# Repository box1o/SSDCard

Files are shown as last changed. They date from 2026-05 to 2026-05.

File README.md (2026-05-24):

# SSDCard 

<p align="center">
  SmartCard Emulator 3D render
</p>

## SmartCard emulator in formfactor of a common Card.
- Size : 85.60 mm × 53.98 mm / reference : ISO/IEC 7810 ID-1 + 50 mm  to the width for the pcb components
- Thickness : 0.76 mm or based on the pcb manufacturer's capabilities

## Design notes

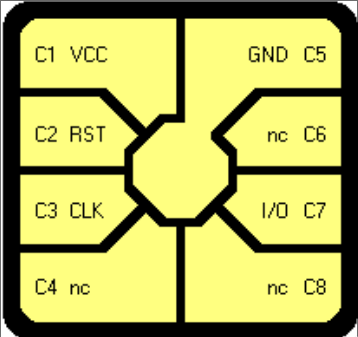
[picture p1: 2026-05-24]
datasheets/pads.png

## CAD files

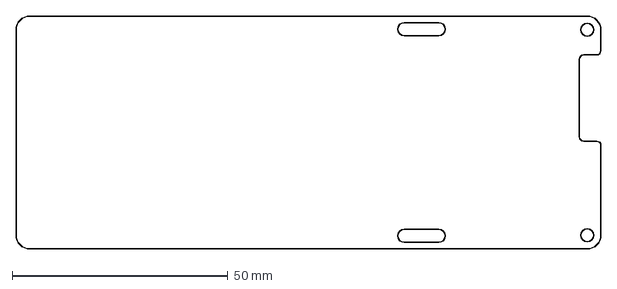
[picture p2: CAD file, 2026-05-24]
mechanical/dxf/BoardOutline.dxf
135.6 x 54.0 mm

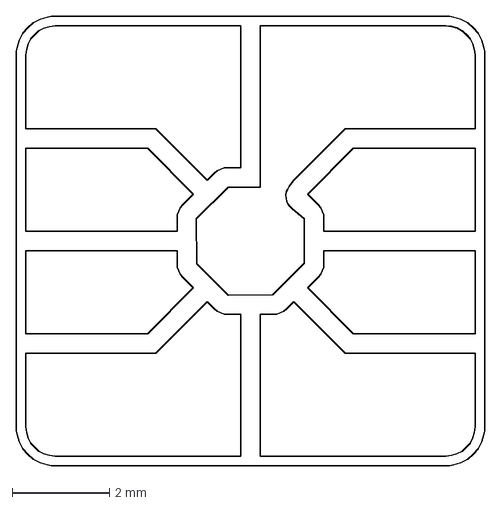
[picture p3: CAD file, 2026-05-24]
mechanical/dxf/cardpads-Sketch-fixed.dxf
9.62 x 9.23 mm

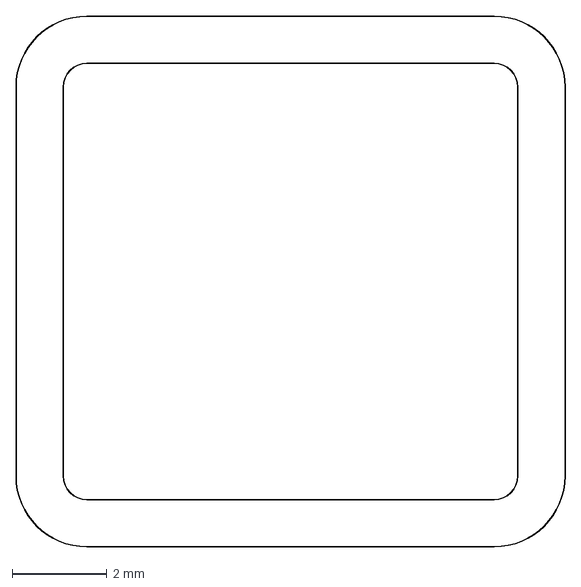
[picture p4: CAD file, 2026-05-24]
mechanical/dxf/ChipOutLine.dxf
11.6 x 11.2 mm

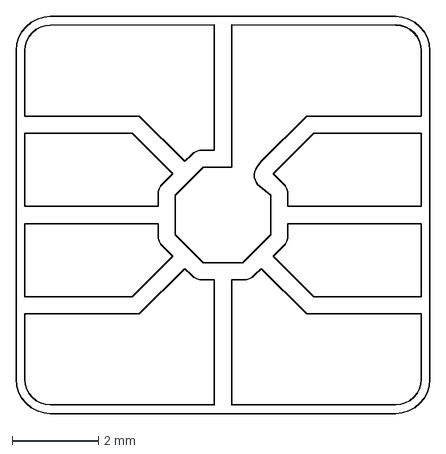
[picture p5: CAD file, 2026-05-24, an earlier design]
mechanical/dxf/outdated.dxf
9.62 x 9.23 mm

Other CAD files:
mechanical/freecad/cardpads.FCStd
mechanical/freecad/Assemple.FCStd

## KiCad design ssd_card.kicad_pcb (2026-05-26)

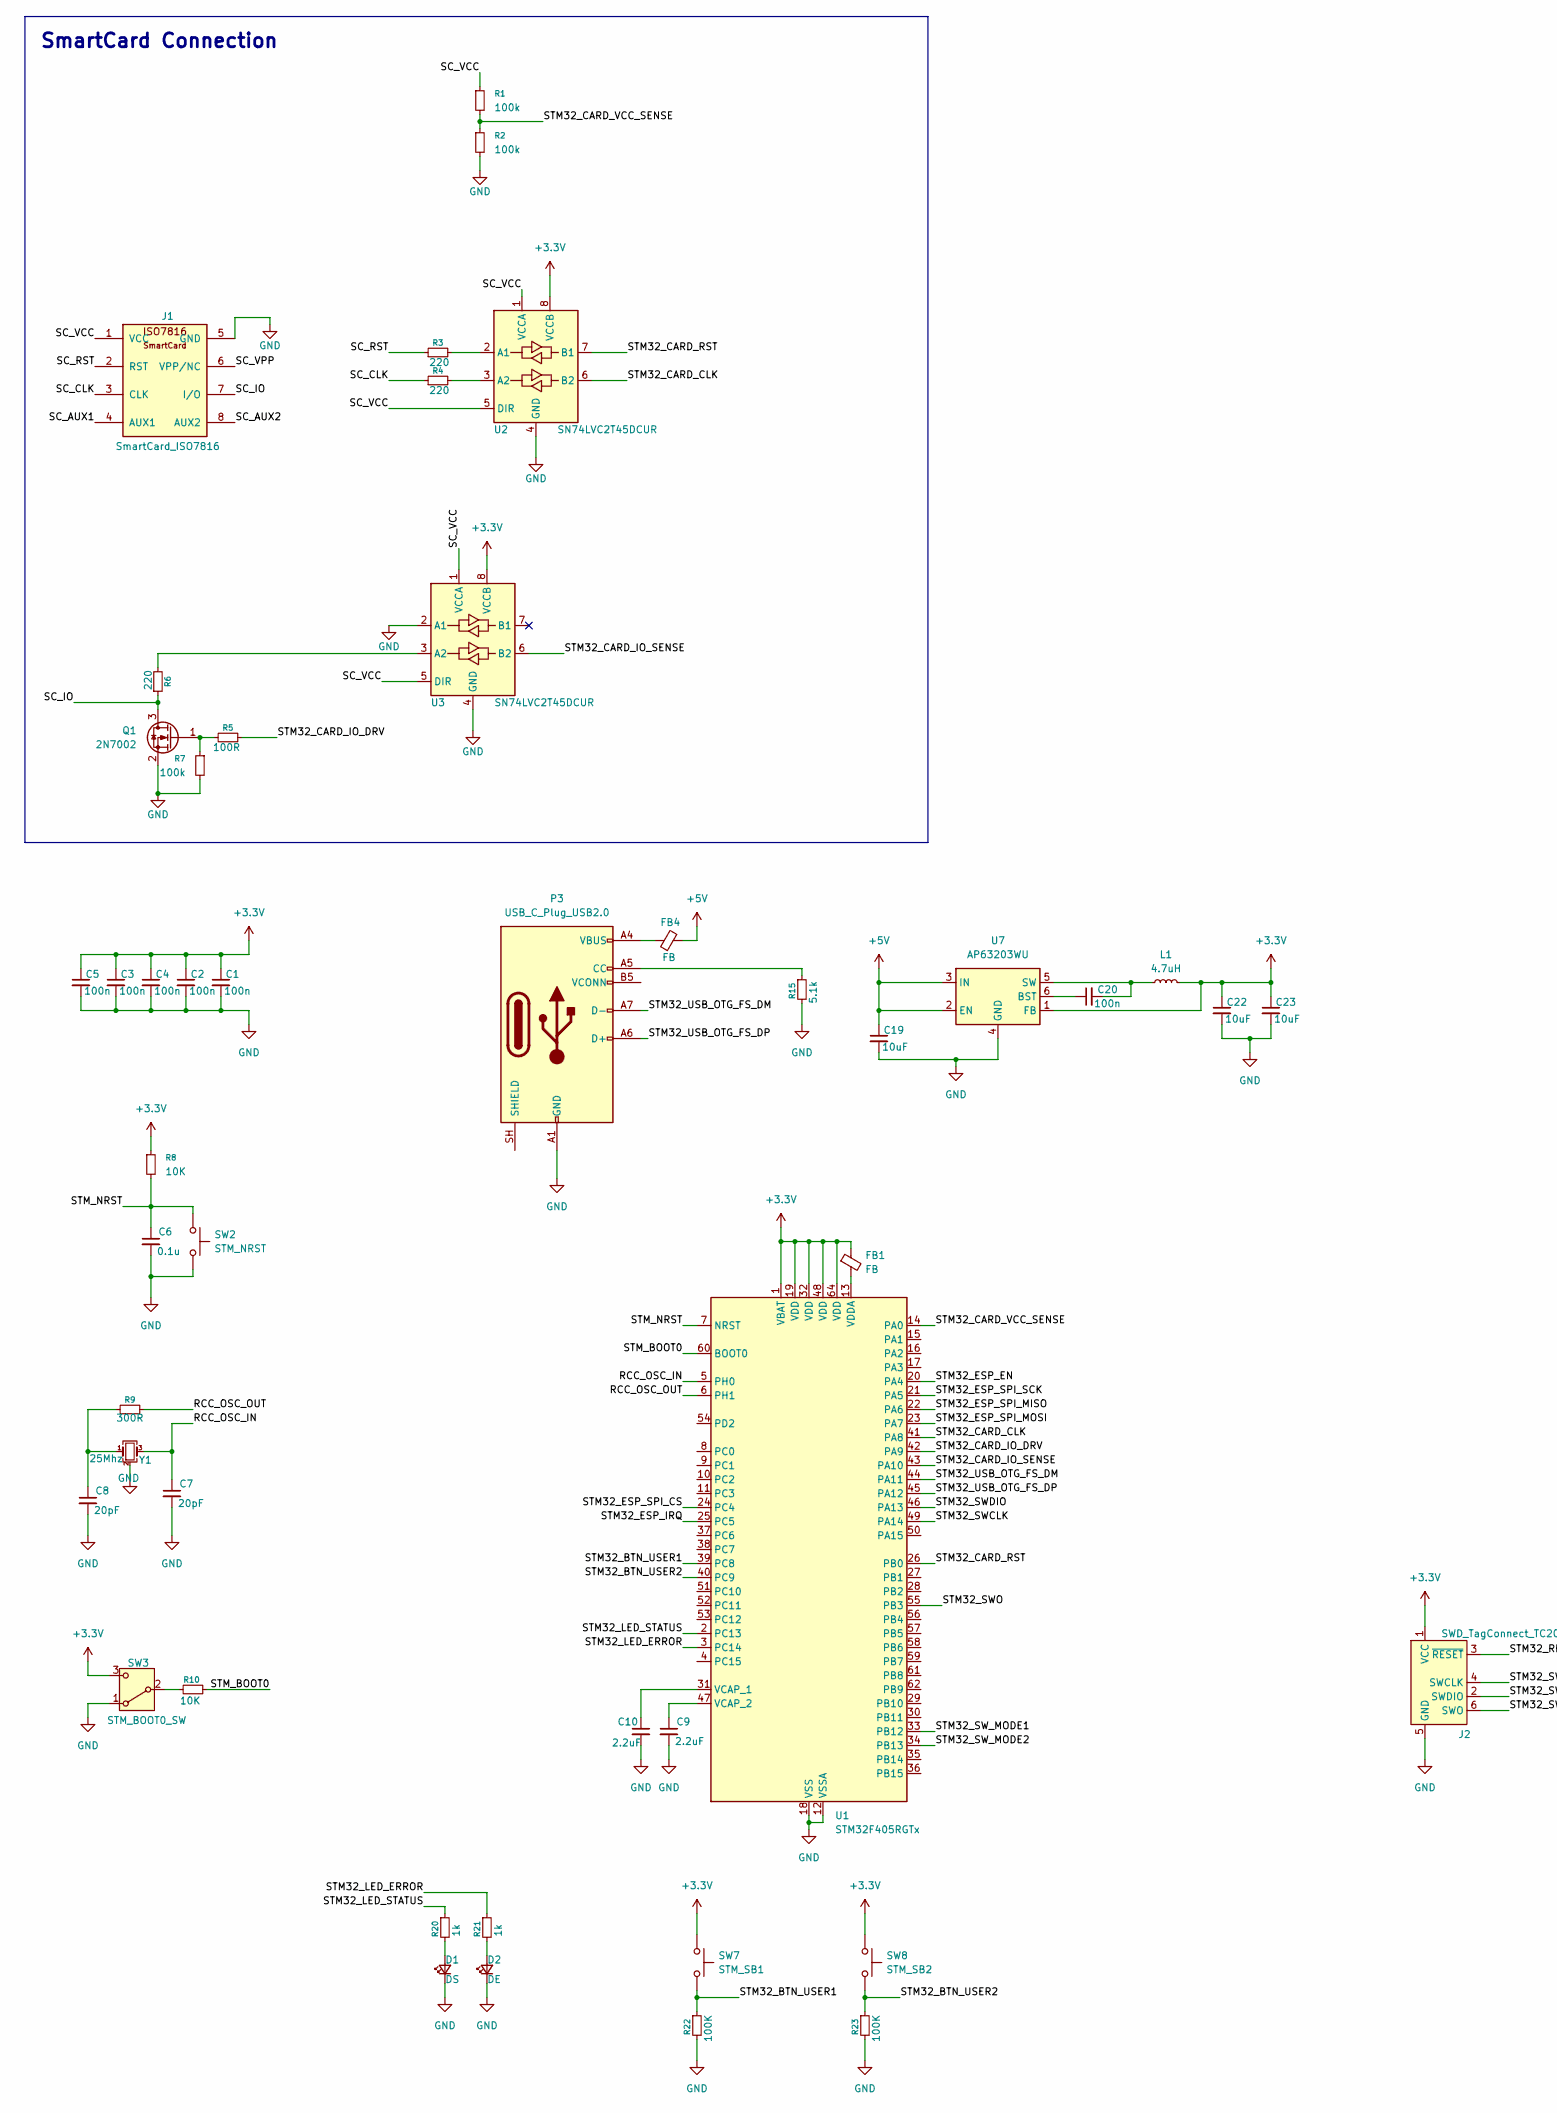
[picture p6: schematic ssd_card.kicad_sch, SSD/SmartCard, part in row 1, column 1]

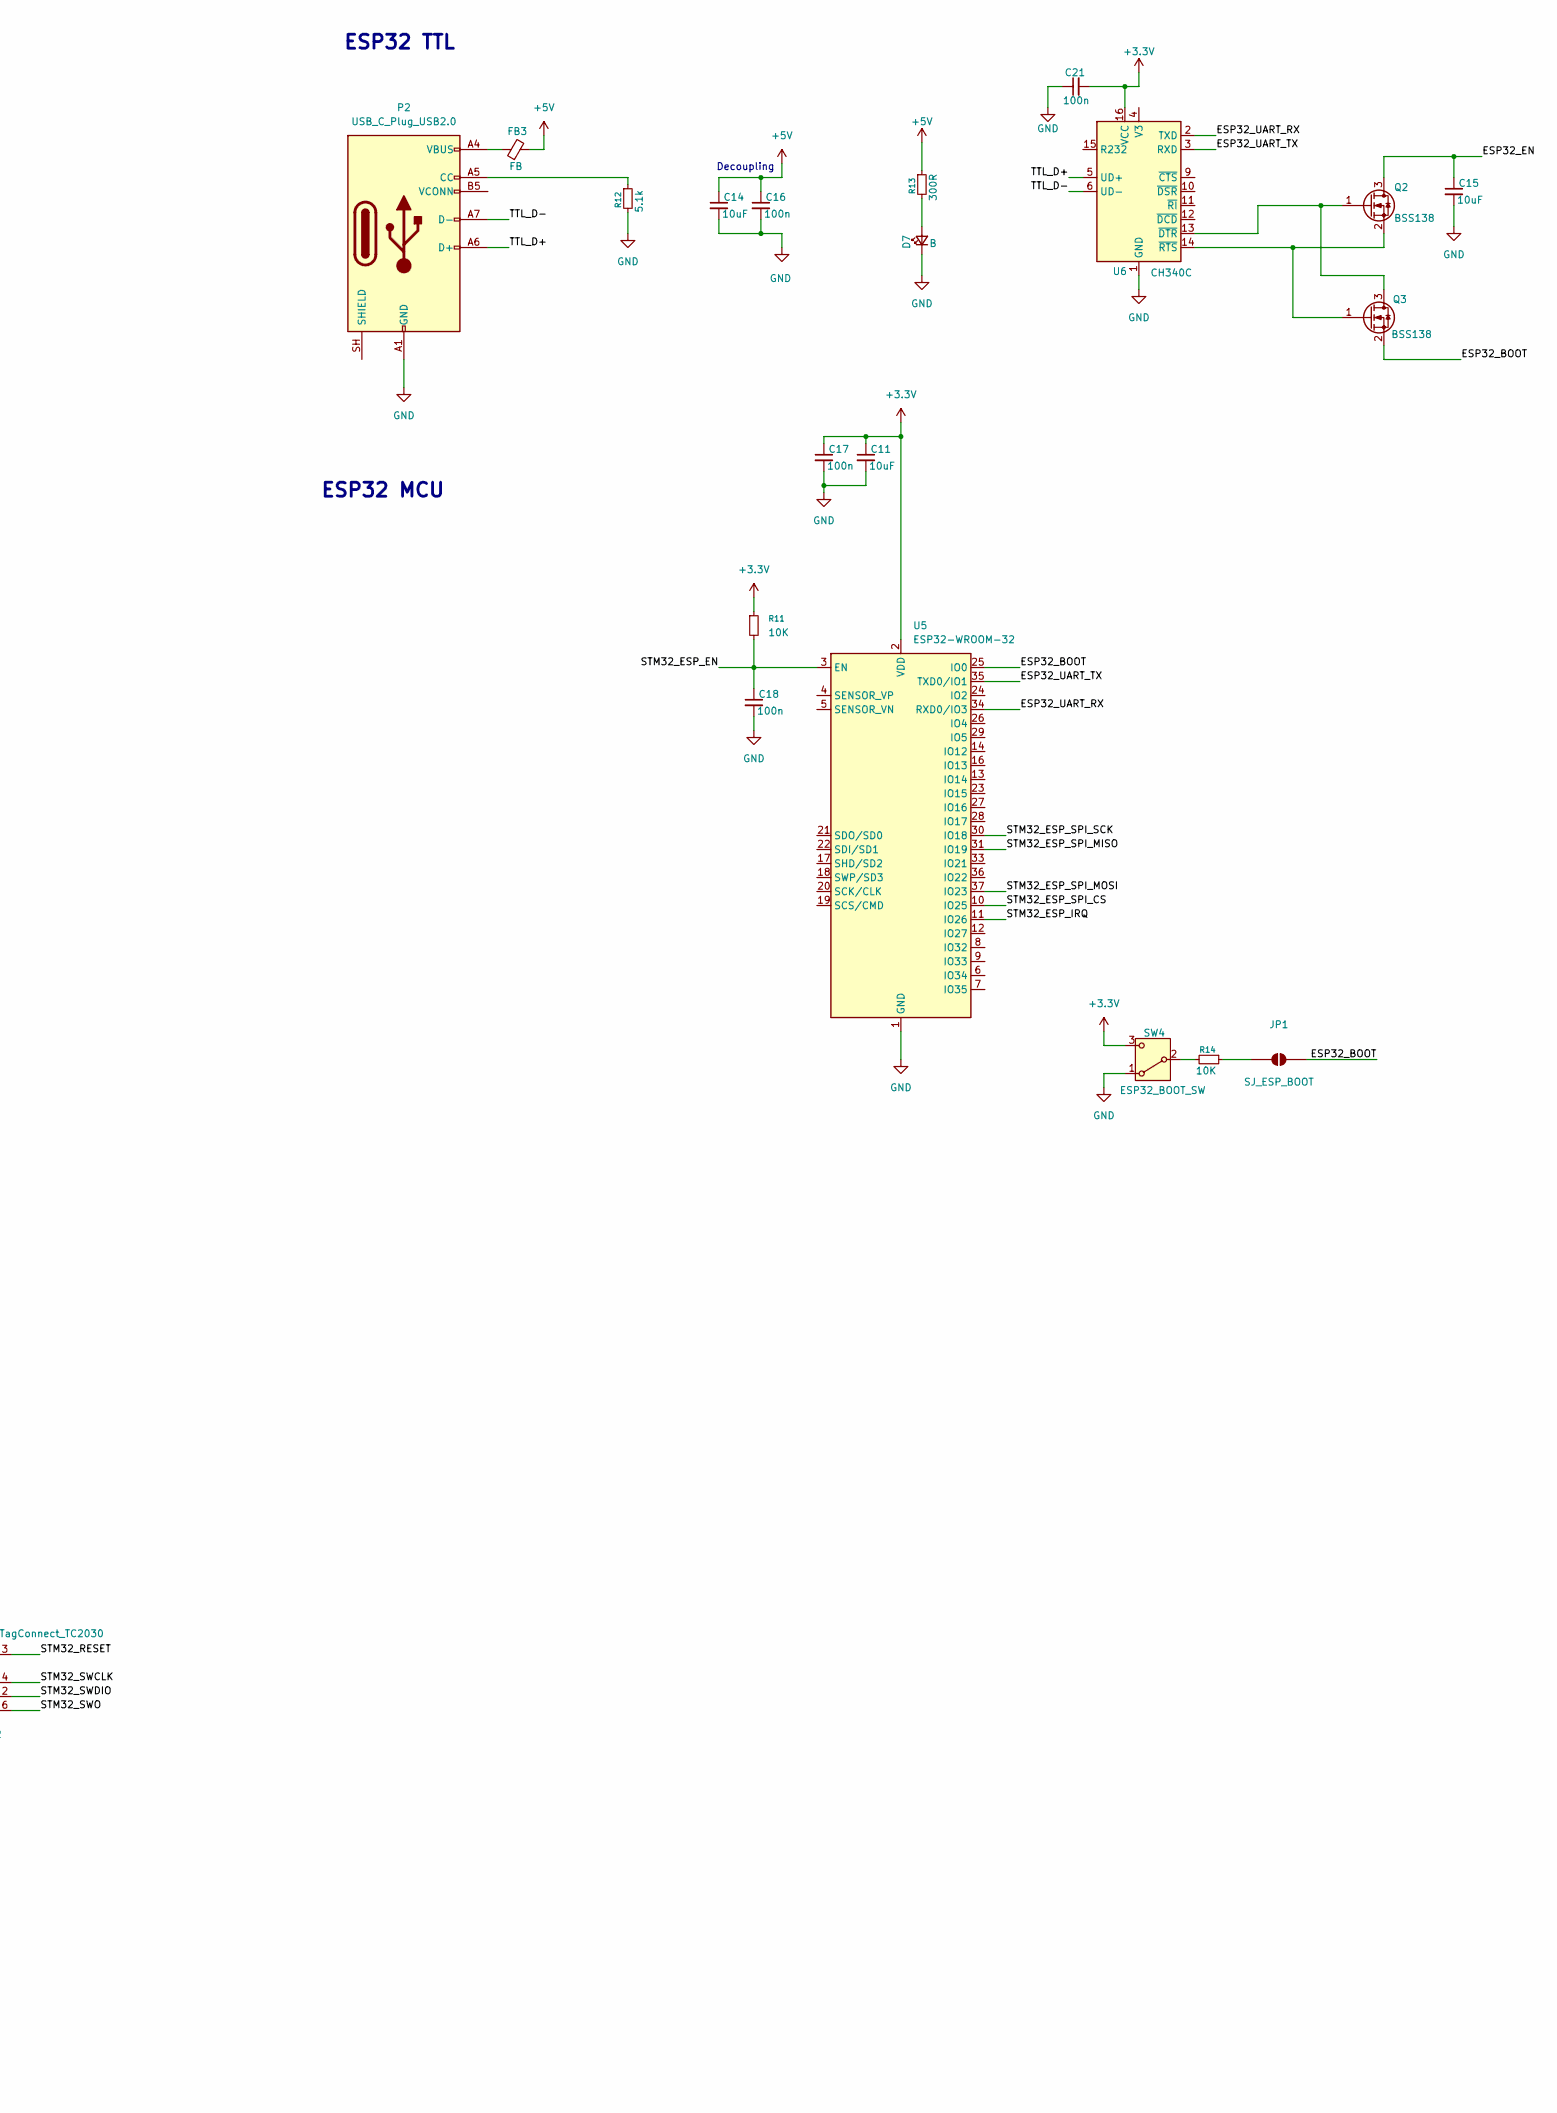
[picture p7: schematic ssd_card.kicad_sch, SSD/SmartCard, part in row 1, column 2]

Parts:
C1, C2, C3, C4, C5, C16, C17, C18, C20, C21: 100n; C_0603_1608Metric
C6: 0.1u; C_0603_1608Metric
C7, C8: 20pF; C_0603_1608Metric
C9, C10: 2.2uF; C_0603_1608Metric
C11, C14, C15, C19, C22, C23: 10uF; C_0603_1608Metric
D1: DS; LED_0603_1608Metric
D2: DE; LED_0603_1608Metric
D7: B; LED_0603_1608Metric
FB1, FB3, FB4: FB; L_0805_2012Metric
J1: SmartCard_ISO7816; ISO7816_CardPads_Clean_Functional
J2: SWD_TagConnect_TC2030; Tag-Connect_TC2030-IDC-NL_2x03_P1.27mm_Vertical
JP1: SJ_ESP_BOOT; SolderJumper-2_P1.3mm_Open_RoundedPad1.0x1.5mm
L1: 4.7uH; L_0805_2012Metric
P2, P3: USB_C_Plug_USB2.0; USB_C_Receptacle_HRO_TYPE-C-31-M-12
Q1: 2N7002; SOT-23
Q2, Q3: BSS138; SOT-23
R1, R2, R7: 100k; R_0603_1608Metric
R3, R4, R6: 220; R_0603_1608Metric
R5: 100R; R_0603_1608Metric
R8, R10, R11, R14: 10K; R_0603_1608Metric
R9, R13: 300R; R_0603_1608Metric
R12, R15: 5.1k; R_0603_1608Metric
R20, R21: 1k; R_0603_1608Metric
R22, R23: 100K; R_0603_1608Metric
SW2: STM_NRST; SW_SPST_B3U-1000P
SW3: STM_BOOT0_SW; SW_SPDT_PCM12
SW4: ESP32_BOOT_SW; SW_SPDT_PCM12
SW7: STM_SB1; SW_SPST_B3U-1000P
SW8: STM_SB2; SW_SPST_B3U-1000P
U1: STM32F405RGTx; LQFP-64_10x10mm_P0.5mm
U2, U3: SN74LVC2T45DCUR; VSSOP-8_2.3x2mm_P0.5mm
U5: ESP32-WROOM-32
U6: CH340C; SOIC-16_3.9x9.9mm_P1.27mm
U7: AP63203WU; TSOT-23-6
Y1: 25Mhz

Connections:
+3.3V: C1.1, C2.1, C3.1, C4.1, C5.1, C11.1, C17.1, C21.2, C22.1, C23.1, FB1.1, J2.1 (VCC), L1.2, R8.1, R11.1, SW3.3 (C), SW4.3 (C), SW7.1, SW8.1, U1.1 (VBAT), U1.19 (VDD), U1.32 (VDD), U1.48 (VDD), U1.64 (VDD), U2.8 (VCCB), U3.8 (VCCB), U5.2 (VDD), U6.16 (VCC), U7.1 (FB)
+5V: C14.1, C16.1, C19.1, FB3.2, FB4.2, R13.1, U7.2 (EN), U7.3 (IN)
/ESP32_BOOT: JP1.2 (B), Q3.2 (S), U5.25 (IO0)
/ESP32_EN: C15.1, Q2.3 (D)
/ESP32_UART_RX: U5.34 (RXD0/IO3), U6.2 (TXD)
/ESP32_UART_TX: U5.35 (TXD0/IO1), U6.3 (RXD)
/RCC_OSC_IN: C7.1, U1.5 (PH0), Y1.3
/RCC_OSC_OUT: R9.1, U1.6 (PH1)
/SC_AUX1: J1.4 (AUX1)
/SC_AUX2: J1.8 (AUX2)
/SC_CLK: J1.3 (CLK), R4.1
/SC_IO: J1.7 (I/O), Q1.3 (D), R6.1
/SC_RST: J1.2 (RST), R3.1
/SC_VCC: J1.1 (VCC), R1.1, U2.1 (VCCA), U2.5 (DIR), U3.1 (VCCA), U3.5 (DIR)
/SC_VPP: J1.6 (VPP/NC)
/STM32_BTN_USER1: R22.1, SW7.2, U1.39 (PC8); also elsewhere on the board
/STM32_BTN_USER2: R23.1, SW8.2, U1.40 (PC9); also elsewhere on the board
/STM32_CARD_CLK: U1.41 (PA8), U2.6 (B2)
/STM32_CARD_IO_DRV: R5.1, U1.42 (PA9)
/STM32_CARD_IO_SENSE: U1.43 (PA10), U3.6 (B2)
/STM32_CARD_RST: U1.26 (PB0), U2.7 (B1)
/STM32_CARD_VCC_SENSE: R1.2, R2.1, U1.14 (PA0)
/STM32_ESP_EN: C18.1, R11.2, U1.20 (PA4), U5.3 (EN)
/STM32_ESP_IRQ: U1.25 (PC5), U5.11 (IO26)
/STM32_ESP_SPI_CS: U1.24 (PC4), U5.10 (IO25)
/STM32_ESP_SPI_MISO: U1.22 (PA6), U5.31 (IO19)
/STM32_ESP_SPI_MOSI: U1.23 (PA7), U5.37 (IO23)
/STM32_ESP_SPI_SCK: U1.21 (PA5), U5.30 (IO18)
/STM32_LED_ERROR: R21.1, U1.3 (PC14)
/STM32_LED_STATUS: R20.1, U1.2 (PC13)
/STM32_RESET: J2.3 (~RESET)
/STM32_SWCLK: J2.4 (SWCLK), U1.49 (PA14)
/STM32_SWDIO: J2.2 (SWDIO), U1.46 (PA13)
/STM32_SWO: J2.6 (SWO), U1.55 (PB3)
/STM32_SW_MODE1: U1.33 (PB12)
/STM32_SW_MODE2: U1.34 (PB13)
/STM32_USB_OTG_FS_DM: P3.A7 (D-), U1.44 (PA11)
/STM32_USB_OTG_FS_DP: P3.A6 (D+), U1.45 (PA12)
/STM_BOOT0: R10.1, U1.60 (BOOT0)
/STM_NRST: C6.1, R8.2, SW2.1, U1.7 (NRST)
/TTL_D+: P2.A6 (D+), U6.5 (UD+)
/TTL_D-: P2.A7 (D-), U6.6 (UD-)
GND: C1.2, C2.2, C3.2, C4.2, C5.2, C6.2, C7.2, C8.2, C9.2, C10.2, C11.2, C14.2, C15.2, C16.2, C17.2, C18.2, C19.2, C21.1, C22.2, C23.2, D1.1 (K), D2.1 (K), D7.1 (K), J1.5 (GND), J2.5 (GND), P2.A1 (GND), P2.A12 (GND), P2.B1 (GND), P2.B12 (GND), P3.A1 (GND), P3.A12 (GND), P3.B1 (GND), P3.B12 (GND), Q1.2 (S), R2.2, R7.2, R12.2, R15.2, R22.2, R23.2, SW2.2, SW3.1 (A), SW4.1 (A), U1.12 (VSSA), U1.18 (VSS), U1.63 (VSS), U2.4 (GND), U3.2 (A1), U3.4 (GND), U5.1 (GND), U5.15 (GND), U5.38 (GND), U5.39 (GND), U6.1 (GND), U7.4 (GND), Y1.2 (G), Y1.4 (G)
unnamed: C8.1, R9.2, Y1.1
unnamed: D1.2 (A), R20.2
unnamed: D2.2 (A), R21.2
unnamed: D7.2 (A), R13.2
unnamed: FB3.1, P2.A4 (VBUS), P2.A9 (VBUS), P2.B4 (VBUS), P2.B9 (VBUS)
unnamed: FB4.1, P3.A4 (VBUS), P3.A9 (VBUS), P3.B4 (VBUS), P3.B9 (VBUS)
unnamed: JP1.1 (A), R14.1
unnamed: P2.A5 (CC), R12.1
unnamed: P3.A5 (CC), R15.1
unnamed: Q1.1 (G), R5.2, R7.1
unnamed: Q2.1 (G), Q3.3 (D), U6.13 (~DTR)
unnamed: Q2.2 (S), Q3.1 (G), U6.14 (~RTS)
unnamed: R10.2, SW3.2 (B)
unnamed: R14.2, SW4.2 (B)
unnamed: C10.1, U1.31 (VCAP_1)
unnamed: C9.1, U1.47 (VCAP_2)
unnamed: FB1.2, U1.13 (VDDA)
unnamed: R3.2, U2.2 (A1)
unnamed: R4.2, U2.3 (A2)
unnamed: R6.2, U3.3 (A2)
unnamed: C20.1, U7.6 (BST)
unnamed: C20.2, L1.1, U7.5 (SW)

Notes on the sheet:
SmartCard Connection
ESP32 TTL
Decoupling
ESP32 MCU

Board: 2 copper layers, 68 parts (0 on the bottom side), 59 nets, no tracks yet.

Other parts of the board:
R18, R19: 10K; R_0603_1608Metric

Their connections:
/STM32_BTN_USER1: R18.1; also elsewhere on the board
/STM32_BTN_USER2: R19.1; also elsewhere on the board

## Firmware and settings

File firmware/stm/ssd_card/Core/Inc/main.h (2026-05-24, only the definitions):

#define LED_STATUS_Pin GPIO_PIN_13
#define LED_STATUS_GPIO_Port GPIOC
#define LED_ERROR_Pin GPIO_PIN_14
#define LED_ERROR_GPIO_Port GPIOC
#define CARD_VCC_SENSE_Pin GPIO_PIN_0
#define CARD_VCC_SENSE_GPIO_Port GPIOA
#define ESP_EN_Pin GPIO_PIN_4
#define ESP_EN_GPIO_Port GPIOA
#define ESP_SPI_SCK_Pin GPIO_PIN_5
#define ESP_SPI_SCK_GPIO_Port GPIOA
#define ESP_SPI_MISO_Pin GPIO_PIN_6
#define ESP_SPI_MISO_GPIO_Port GPIOA
#define ESP_SPI_MOSI_Pin GPIO_PIN_7
#define ESP_SPI_MOSI_GPIO_Port GPIOA
#define ESP_SPI_CS_Pin GPIO_PIN_4
#define ESP_SPI_CS_GPIO_Port GPIOC
#define ESP_IRQ_Pin GPIO_PIN_5
#define ESP_IRQ_GPIO_Port GPIOC
#define CARD_RST_Pin GPIO_PIN_0
#define CARD_RST_GPIO_Port GPIOB
#define CARD_RST_EXTI_IRQn EXTI0_IRQn
#define SW_MODE1_Pin GPIO_PIN_12
#define SW_MODE1_GPIO_Port GPIOB
#define SW_MODE2_Pin GPIO_PIN_13
#define SW_MODE2_GPIO_Port GPIOB
#define BTN_USER1_Pin GPIO_PIN_8
#define BTN_USER1_GPIO_Port GPIOC
#define BTN_USER2_Pin GPIO_PIN_9
#define BTN_USER2_GPIO_Port GPIOC
#define CARD_CLK_Pin GPIO_PIN_8
#define CARD_CLK_GPIO_Port GPIOA
#define CARD_IO_DRV_Pin GPIO_PIN_9
#define CARD_IO_DRV_GPIO_Port GPIOA
#define CARD_IO_SENSE_Pin GPIO_PIN_10
#define CARD_IO_SENSE_GPIO_Port GPIOA

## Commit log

2026-05-24 feat: add ISO 7816 card outline boundaries and pad symbols
    [Assemple.FCStd, BoardOutline.dxf, ChipOutLine.dxf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]
2026-05-24 fix: vendor smartcard KiCad library
2026-05-24 ci: trigger PCB release from dev
2026-05-24 feat: STM32 firmware/pin config
    [ssd_card.kicad_pcb]
2026-05-24 feat: STM32 start schematic
    [ssd_card.kicad_sch]
2026-05-25 feat: Documentation
    [iso7816_meganorm_latest_manifest.csv, ssd_card.kicad_sch]
2026-05-25 feat: iso7816
    [iso7816_meganorm_latest_manifest.csv]
2026-05-26 ci: make PCB release manual only
2026-05-26 Add HRO USB-C receptacle footprint
    [ssd_card.kicad_pcb, ssd_card.kicad_sch]

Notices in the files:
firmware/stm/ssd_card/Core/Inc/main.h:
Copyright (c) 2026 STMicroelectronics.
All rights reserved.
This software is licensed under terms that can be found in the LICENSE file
